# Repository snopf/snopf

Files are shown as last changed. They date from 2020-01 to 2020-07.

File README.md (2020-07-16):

# Snopf USB password token

> Info: The password creation algorithm for Snopf has been fundamentally changed since 6b1df42b0c21d2e936d6018c70f1937114251a39. The new firmware and the new tools and account table files aren't compatible with the former version. The command line tool has been deprecated. Snopf also switched from using a 128 bit secret to using a 256 bit secret on the device. For upgrading the firmware you can use the firmware updater from the bootloader repository [here](https://github.com/Snopf/Snopf_bootloader). For installation and configuration follow this readme.

## What is Snopf?

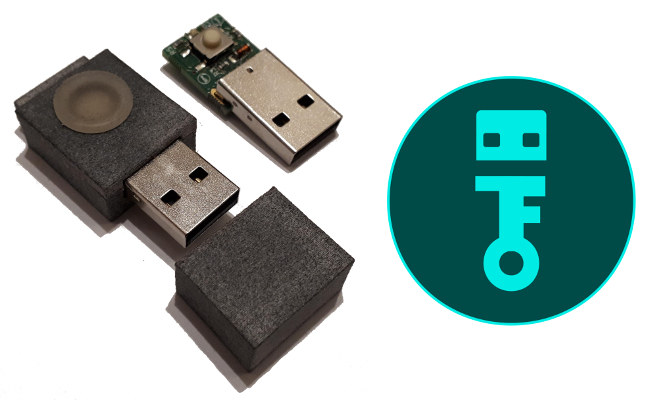
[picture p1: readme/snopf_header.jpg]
Snopf device


Snopf is a very simple, yet effective and easy to use USB password tool. The Snopf USB device creates a unique and strong password for every service from the same 256 bit secret which never leaves the token.

Whenever Snopf is plugged into the computer you can make a password request and then the red LED will light up. If you press the button within 10 seconds Snopf will imitate a keyboard and type the password for the requested service.

Snopf is designed as a hardware-based password generator to tackle the security issues most commonly encountered with stored passwords on ordinary PCs, such as reading of password files by malware or browser exploits. It generates passwords deterministically from a securely kept master secret unaccessible to software running on the host. 

For more details on security and how it works, see the section *Security considerations* and *Operation principle* below.
Instructions on how to build your own are found in the section *Hardware* and *Building the Firmware and Host Software*. A short manual on how to use Snopf after you installed the software is found in *How to use it*.

## Advantages of Snopf

* Very simple and robust design
* Easy to use
* You don't have to remember any passwords anymore (except preferably a master PIN for Snopf)
* Every password is unique and as strong as the accessed service allows
* The actual password creation is only happening on the USB device
* It is (under certain restrictions) possible to restore all passwords from a 24 word mnemonic representing the 256 bit secret
* It's more secure than a common pure software based password manager because the password creation is physically detached from the computer
* As Snopf emulates a regular keyboard, no passwords are stored in the clipboard

### Advantage over Common Software Password Managers
Common software password managers are very good tools to create and manage strong passwords for all your logins. Still, there is a possibility of your computer being remotely attacked and an attacker is able to access your password database getting all your login credentials.
Snopf is an improvement over these managers because an attacker can't access your Snopf token remotely. All passwords are derived from the secret on the device which an attacker must have phyiscal access to. So there is an additional *physical barrier* for an attacker.

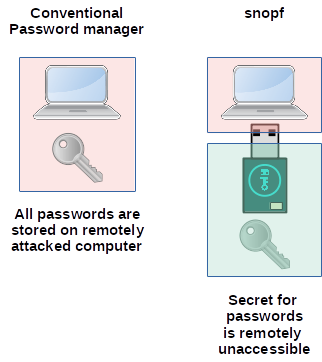
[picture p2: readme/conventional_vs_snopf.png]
conventional_vs_Snopf


## Using Snopf
A default request process for a password is pictured below, using the Snopf browser extension:

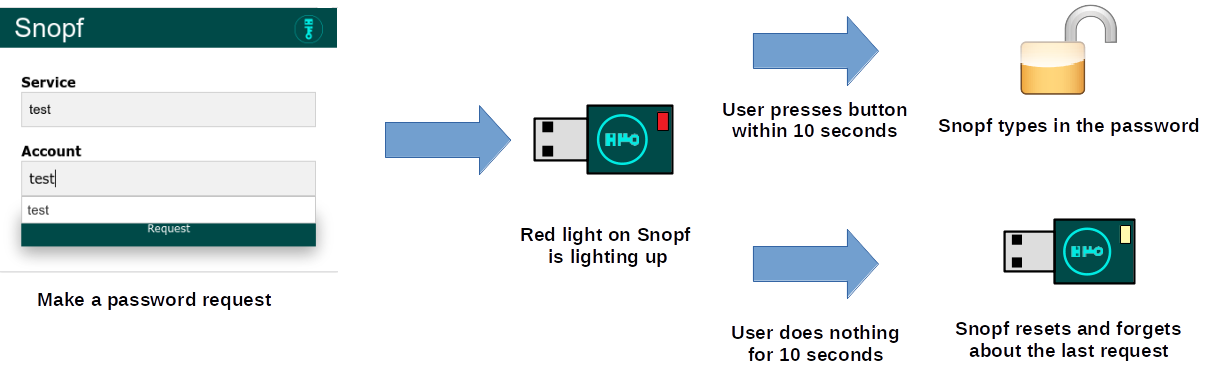
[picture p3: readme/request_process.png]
request_process


To use Snopf two tools are currently available (an additional Android App is being developed), the *Snopf Manager* and a browser extension.

The Snopf Manager needs to be running on a computer when using Snopf. Beside managing the account table for snopf (see below) it also runs a background server for the browser extension. Whenever a password request is made in the browser, it is sent to the server which in turn talks to the USB device. The Snopf Manager minimizes to tray and runs silently in the background if you are not currently editing the account table. You can also create new entries in the account table from the browser extension.

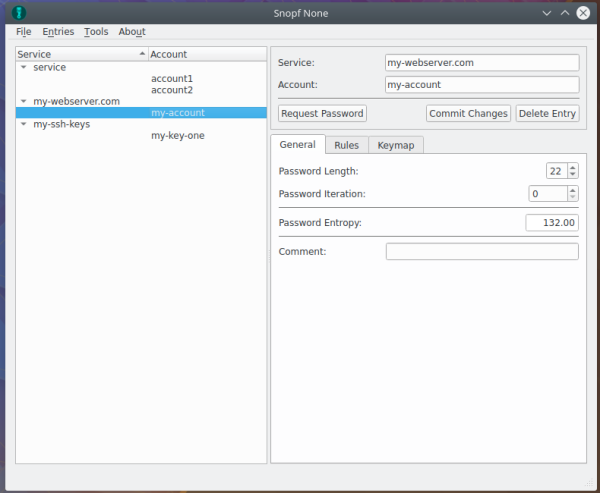
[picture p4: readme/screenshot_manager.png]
snopf manager screenshot


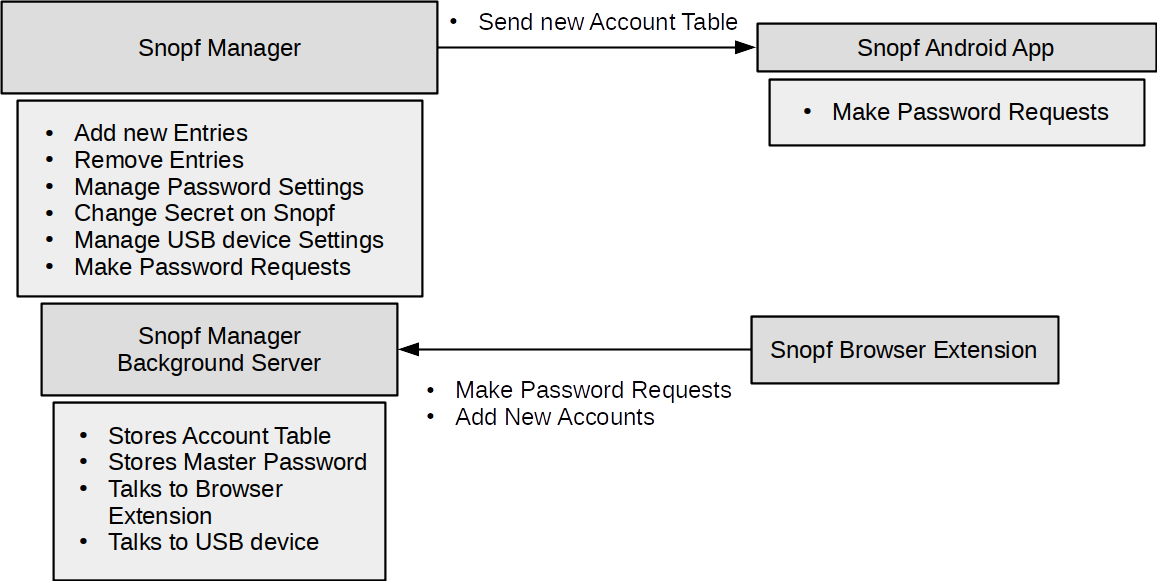
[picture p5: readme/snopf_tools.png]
snopf tool overview


### Account table
With Snopf Manager you can create new entries, delete entries and change entries in the account table. A Snopf account table is a simple json with entries for every unique (service, account) combination. Each entry has six fields:

1. `Service` = Hostname or service name for the login, for example the email service `examplemail.com`
2. `Account` = Your account at this service, for example the email address for the email service `my_mail_address@examplemail.com`
3. `Password length` = The password length you set for this service
4. `Password iteration` = An integer for every unique (service, account) combination which you increase if you have to set a new password for this combination for example after a databreach at the used service.
5. `Rules` = Rules for password creation, for example 'The password must include a lowercase character'
6. `Keymap` = A keymap which will be used for the password creation which allows to include and exclude certain characters

The account table file is AES encrypted on the hard disk using the same master password (not to be confused with the secret on the USB device!) that is used whenever a password request is submitted.

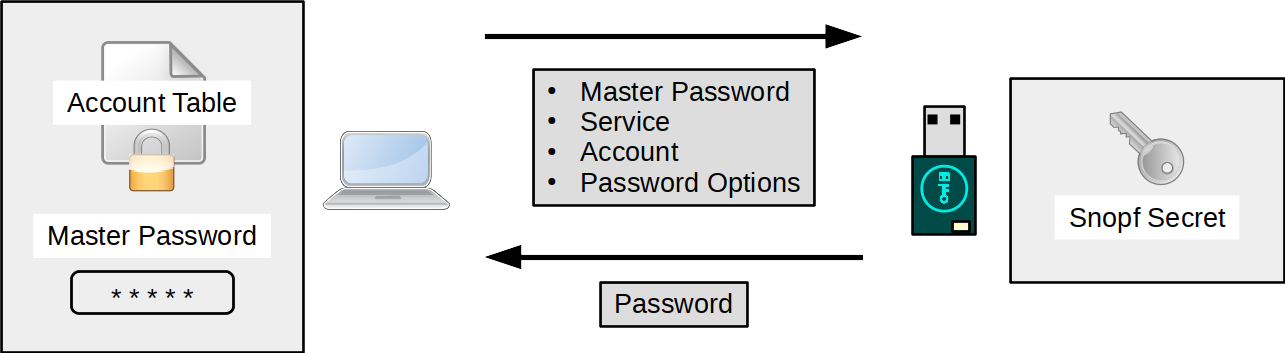
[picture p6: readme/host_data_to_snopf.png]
host_data_to_snopf


#### Setting the secret
You can change the secret on the Snopf device using Snopf Manager.

## Restoring passwords

To restore passwords, for example after losing or damaging Snopf, you need to be in possesion of the following data:

1. The Snopf's secret (comfortably as a 24 word mnemonic)
2. The optional master password (if you used one)
3. The account table

You might not absolutely need the account table if you have your logins, like email address and email service in your memory and just used passwords with default settings. Even if you need to remember *password iteration* you can just try out low numbers there.

Apart from that it is strongly advised to backup the account table and use a master password that you can remember. You should write down the 24 word mnemonic for the Snopf secret and store at a safe place.

With the above information you will be able to recreate all your passwords.

## Security considerations
Snopf isn't 100 % secure and a certain tradeoff between security, usability and economics has been made. Make sure to use Snopf only with your own or trusted PCs. It is also assumed that an adversary does not come into physical possesion of your Snopf. However, in case Snopf gets lost or is stolen, a reasonable safe master passphrase (the two-factor authentication approach) will still fend off or at least slow the attacker, depending on the strength of this passphrase.

Snopf has not been designed or further analyzed vs. more advanced attacks such as power analysis or timing side-channel attacks and could be theoretically vulnerable to either. Attacks of this and similar kinds are deemed outside the scope of the threat model that Snopf defends against. So far, regular computers don't seem to allow detailed current measurement at their USB ports which could potentially be used for remote attacks. More sophisticated attacks such as relying on analyzing the microcontroller's electromagnetic emissions are not deemed a common threat.
Timing attacks are similarly not expected to be a huge issue. The SHA256 crypto primitive used by Snopf runs in constant time. The iterated hashing to yield a password matching "password_valid" will cause some timing variation for a minority of passworts. However, as Snopf relies on a *manual* button press for replying with the password, a large amount of noise is added and makes analyses along this line a lot less feasible.

The ATtiny85 does not include a secure enclave (or similar) and reading out the microcontroller might be possible if an attacker has physical access. It can be made harder by setting the lockbits for the AVR but a capable attacker will be able to access the EEPROM data (where the secret is stored) eventually. A reasonable safe master passphrase will still prevent logins by an attacker at least for some time to create new passwords.

Passwords typed in by Snopf can of course still be intercepted by a keylogger and might land in the RAM and swap memory of the host where malware might access them. Covering those attack vectors is likewise out of scope for Snopf.
 
## Password Creation Algorithm
The password creation algorithm is explained in-depth [here](readme/password_algo.pdf).

## Hardware
You can find a KiCad project for Snopf in the `hardware` subfolder and also a PDF of the current schematic [here](https://github.com/Snopf/Snopf/blob/master/readme/schematic.pdf). The KiCad project also includes a PCB layout for a SMD version.

Bill of materials for the SMD version:
* ATTINY85-20SU SO(1)
* Resistor 10k 0603 (1)
* Resistor 220R 0603 (1)
* Resistor 1k 0603 (1)
* Resistor 1k5 0603 (1)
* Resistor 68R 0603 (2)
* Capacitor 18pF 0603 (2)
* Capacitor 100n 0603 (1)
* Capacitor 4u7 0805 (1)
* Crystal 12 Mhz 4 Pin (1)
* LED red 0603 (1)
* USB connector (1)
* Zener Diode 3,6V Mini Melf (2)
* Button Panasonic EVQQ2 (1)

There are links for Mouser parts that work for the PCB layout to be found in the KiCad schematic.

## Casing
A 3D printable casing can be found at `hardware/casing` both as a FreeCAD file and as four STEP files (bottom, top, button and a cap for the USB plug). The button is designed as a silicone button so that the diffuse LED light can been seen through it.
The dimensions of the casing are 41.9 x 19.4 x 11 mm.

## Running and building the Snopf software

### Python Venv
To avoid bugs and conflicts due to different versions of installed python packages it is advised to initialize a Python virtual enviroment for all operations described in this section. This includes running the python code as well as building binaries for either the AVR or the PC. Alternatively you can have a look at `src/py_requirements.txt` to see which Python packages and which versions are used for Snopf and install them accordingly.
To create a Python Venv you can simpy run
```
$ ./setup_py_env.sh
```
in the Linux console and
```
$ ./setup_py_env.ps1
```
in the Windows PowerShell. This will create a `.venv` directory with all necessary packages installed and activate that virtual enviroment for the current session.
To activate the virtual enviroment for the current session you run
```
$ source .venv/bin/activate
```
in the Linux console and
```
$ ./.venv/scripts/activate.ps1
```
in the Windows PowerShell.

### Linux udev rule
There is an udev rule for allowing USB acces to Snopf located in `src/host` which you can copy to `/etc/udev/rules.d` or you can simply run
```
$ ./install_usb_rule.sh
```

### Building the Firmware
You can compile the AVR code and program the AVR using the standard GNU toolchain using
```
$ make program
```
in the avr source directory `src/avr`. You'll probably have to alter the `Makefile` for your kind of programmer.

There also exists a bootloader written for this project, you can find it here [Snopf bootloader](https://github.com/Snopf/Snopf_bootloader) so that you can update the code on the device via USB. The bootloader is not necessary but it comes in handy for updating the firmware.

### Running the Snopf Manager Python code
After activating the Python virtual enviroment you can run the QT app as a Python script by running
```
python snopf.py
```
in `src/host/pc`.

### Building Snopf Manager Binaries for Linux
You can build a stand-alone binary for Snopf using PyInstaller. Just run `make` in `src/host/pc`.
It is advised to run `make` in the Python virtual enviroment to ensure that all needed packages are installed using the correct version.
The output will be created in `src/host/dist`.

### Building Snopf Manager Binaries for Windows
You can build an executable for Windows using the same Makefile as for Linux. You will have to have [GNU make for Windows](http://gnuwin32.sourceforge.net/packages/make.htm) installed. All scripts are written for PowerShell so you have to run Make from PowerShell.
PyInstaller will look for an [UPX](https://upx.github.io/) installation at `3rdparty/upx/`. You can create the binaries with or without using UPX compression.

### Browser extension
The firefox extension is located at `src/host/browser_extension` and can be packed into a zip file suitable for the browser by simply running `make` there.

There doesn't exist a signed version for the firefox browser extension yet so to permanently install the addon you would have to change the firefox settings  explictly to allow the installation of unsigned addons.
If you know what you are doing you can do this (for most firefox versions) by opening the 
```
about:config
```
page and set the value for 
```
xpinstall.signatures.required to false.
```
After doing that you can install the zip file under *about:addons*. If you change the setting back to *true* the addon will be deactivated by firefox.

Alternatively you can also temporarily install the addon by entering
```
about:debugging#/runtime/this-firefox
```
into the adress bar and and clicking *Load Temporary Add-on...*.

### Android App
An Android App is in development for the new Snopf algorithm.
<!-- 
The Android App is located at `src/host/android` as an project for `androidstudio` and can be build and applied to an Android phone using the same.
 -->

## Disclaimer
There is no warranty for data security and integrity or security issues of any kind. Care has been taken to make this a device that increases your security, however security bugs are possible.

You are free to use it and copy it but it comes **without any guarantees**.

## Links

* Snopf makes use of the excellent [V-USB driver](https://www.obdev.at/products/vusb/index.html)
* Article about Snopf on [Hackaday](https://hackaday.com/tag/snopf/)

## License
All code and schematics / hardware layouts are licensed under GNU General Public License (GPL) Version 2, see file License.txt.

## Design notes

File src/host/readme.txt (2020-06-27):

To build all programs (qt-tool, browser extensions) just use (being in the python venv!)
$ make

To build specific tools go to the subfolders and run
$ make tool

All binaries are put into dist/

USB rule installation (Linux):
To use the snopf device you should create an entry in /etc/udev/rules.d.
You can just run 
$ sudo ./install_usb_rule.sh
(Needs root privileges for writing to /etc/)

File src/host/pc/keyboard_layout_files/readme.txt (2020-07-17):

This directory contains files for different keyboard layouts that can be programmed into
the Snopf device.

Each file is a json file that includes a tuple of integers (first is key modifier, second is keycode) for each of the 64 characters in the Snopf character table.

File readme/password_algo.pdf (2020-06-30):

## Snopf Password Creation Algorithm

Hajo Kortmann

June 30, 2020

Snopf uses a deterministic algorithm for generating unique and strong passwords for every user login. The only crypto primitive used for generating passwords is SHA256 hashing, every password is essentially a SHA256 hash of the concatenation of the 256 bit secret stored on the Snopf device and a 128 bit request message which is unique for each password request.
Some services have different rules for valid passwords, for example the password must include a special character or a number. Passwords are iteratively generated until the created password meets the specific requirements for a given password request.

Variables

We introduce the short names S for the 32 byte secret on the Snopf and W for the final result of the password creation algorithm. W is a sequence of printable characters.

Data sent by the Host

For every password request the host must send the following data to the device:

1. M, the unique request message, a sequence of 16 bytes
2. l, an integer defining the length of the generated password
3. R, a set of the character inclusion rules (each rule is a set of characters)
4. rrep, boolean variable; if True the password must not include repeated characters (e.g. ’aa’)
5. rseq, boolean variable; if True the password must not include sequences of characters (e.g. ’abc’)
6. K, the keymap for the request, a sequence of integers of length 64

Request Message The request message must have a length of 16 bytes. It is defined as

M := first 16 bytes of SHA256 (service || account || master_passphrase || iteration)

Here service is the name of the service we want to log in to, account is our username or other account identifier for the service. The master_passphrase is a passphrase we use for all passwords

1

(might also be empty if the user doesn’t want to use a master passphrase)¹
. The iteration field
is a number for each unique (service, account) combination that is incremented every time a new password has to be created for a service, for example after a data breach at that service. The fields for master_passphrase, service and account are UTF-8 encoded strings without any terminating character like newline or null. iteration is an ASCII string representing the iteration integer.

Password Length The integer l ∈ {6, 7, .., 42} is the length of the generated password. As we use 6 bit for each character and the SHA256 hash is 256 bits long we get the upper limit of 42 characters for the password. The reasoning for the lower boundary is stated below in the section ‘Probability of Algorithm Convergence’.

Character Inclusion Ruleset As many services demand passwords to include characters of certain character groups the ruleset R is submitted. The ruleset R may include any of the following sets of characters which define which characters must be included:

1. The password must include a lowercase character, Rlc = {‘a’, ‘b’, .., ‘r’}
2. The password must include an uppercase character, Ruc = {‘A’, ‘B’, .., ‘R’}
3. The password must include a numerical character, Rnum = {‘0’, ‘1’, .., ‘9’}
4. The password must include a special character, Rsc = {‘-’, ‘@’, .., ‘>’}

These character sets are later used to test whether the password includes any element of the submitted rules.

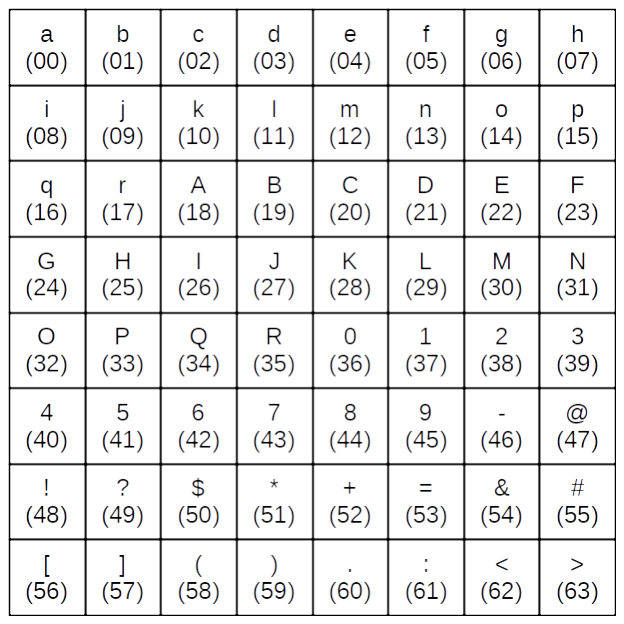
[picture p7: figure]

Figure 1: Snopf Character Set

Keymap The first step of processing the SHA256 output is the Base64²
transformation of the
hash digest into a sequence of integers in the range {0, 1, .., 63}. We could directly map this result

1Note that master passphrase and master secret are two independent variables. The master secret is the 256 bit secret stored on the Snopf device while the (optional) master password is a user input.
2Here we do not use the standard Base64 transformation definition where the output is a sequence of characters. The Base64 transformation in this context is the transformation of an input bit stream into a sequence of integers in the range {0, 1, .., 63} using 6-bit chunks of the input stream.

2

to a sequence of characters using the character table C shown in figure 1 but to allow the definite exclusion of characters from the output sequence we use the keymap K. Using K we simply map the k-th integer i from the Base64 sequence to the k-th character in W:

Wk = C(K(i))

We require 0 ≤ K(i) ≤ 63 for all 0 ≤ i ≤ 63.
While C and the Base64 transformation are both bijective this often won’t be the case for keymaps except the standard keymap where K(i) = i. For example, if we wanted to exclude all characters except lowercase letters the keymap would be defined as

Klc(i) = i mod 18

and for only numerical characters as

Knum(i) = (i mod 10) + 36

and so on. The keymap chosen thus influences the entropy per character of W, see below at ‘Password Entropy’.

Keymap validity for given rules The password creation rules defined above limit the creation of valid keymaps. If rrep is selected we obviously must have more than one value in K. To be able to avoid sequences we must either have a keymap with only one entry or more than two. For simplicity a keymap is defined as valid if it includes more than two different values.
Each value of K belongs to one of the four character groups (lowercase, uppercase, numerical, special character). The size of the subset of the image of K must be at least ten for every character group where a must-inclusion-rule is selected. This limit is needed to guarantee convergence of the iterative algorithm, see below in ‘Probability of Algorithm Convergence’.

## Iterative Password Algorithm

To create a valid password for a given request we use an iterative algorithm where we manipulate the first byte of the request message as often as needed until the SHA256 hash output will produce a valid password according to the selected rules.
First, we define the function replace_characters which, according to the submitted rules, replaces repetitions or sequences of characters. Note that this function only converges given the boundary conditions above about the size of the keymap.
Further, we define the function password_valid(W, R) which returns True if the password is valid according to the inclusion rules in R. A valid password includes at least one element of each set in R.
The iterative password generation algorithm assumes that all passed parameters guarantee the convergence of the algorithm in less than 256 iterations. We treat the request message M as an integer sequence M = (m0, m1, .., m15). To find a password we manipulate m0 until the SHA256 hash results in a valid password according to the rules. The probability of the convergence of this algorithm is calculated in the following section.

3

Algorithm 1: Repetition and sequence replacement
function replace_characters;
Input : Integer sequence B of Length l, Keymap K, Boolean variables rrep, rseq Output: Integer sequence B⁰ where every C(K(B⁰
i

)) 6= C(K(B⁰
i−1

)) if rrep = True and
every C(K(B⁰
i

)) 6= C(K(B⁰
i−1

) + 1) if rseq = True
B⁰
0

:= B0
foreach Bi

, 1 ≤ i < l do
B⁰
i

:= Bi
while [rrep ∧ (C(K(B⁰
i

)) = C(K(B⁰
i−1

)))] ∨ [rseq ∧ (C(K(B⁰
i

)) = C(K(B⁰
i−1

)) + 1)] do
Bi

:= (Bi + 1) mod 64
end
end

Algorithm 2: Password valid function
function password_valid;
Input : Password W of length l, Inclusion ruleset R
Output: True if password is valid according to ruleset R, else False Ws = {Wi

| 0 ≤ i < l}
for r in R do
if C ∩ r = ∅ then
return False
end
end
return True

Algorithm 3: Snopf password creation algorithm
Input : Secret S, Request Message M, Password Length l, Inclusion Rule set R, Repetition rule rrep, Sequence rule rseq, Keymap K Output: Character Sequence (Password) W of Length l
for 1 to 256 do
B64 := Base64(SHA256(S || M)) replace_characters(B64, rrep, rseq, K)
W := C(K(B64))
if password_valid(W, R) then return W
end
m0 = (m0 + 1) mod 256
end
return Failure

4

Probability of Algorithm Convergence

There is a – for the chosen boundary conditions only theoretical – chance for the password creation algorithm to fail or rather need an unreasonable number of iterations to find a valid password. We assume the process of finding a password to be following a geometric distribution since repeated SHA256 hashing of the manipulated data is assumed to be a memoryless process with uniform random output in this context. The probability p of a success at a single attempt is calculated from the experimentally found mean of needed attempts µ:

p = 1/µ

The probability of needing X ≤ n attempts for a success is then calculated by:

P(X ≤ n) = 1 − (1 − p)

n

To find µ, 100,000 passwords for each password length setting were created; with different random inputs for S and M at each try.
To test the worst case scenario all character inclusion rules were used for testing algorithm convergence (R = {Rlc, Ruc, Rnum, Rsc}). Also an unbalanced keymap was used, which included just 10 (minimum number) entries for three of the rules, thus lowering the chance for a certain character to be included in the output.
In table 1 we can see that there is only a theoretical chance for the algorithm to fail given the shortest possible password of length l = 6. For l > 6 we rarely need more than 2 tries to find a valid password.
Password length | mean | 1 − P(k = 1) | 1 − P(k ≤ 10) | 1 − P(k ≤ 255)
6 | 4.8 | 0.7922 | 0.0974 | 0.0
10 | 1.9 | 0.4748 | 0.5816e-3 | 0.0
20 | 1.1 | 0.0951 | 0.606e-12 | 0.0

Table 1: Probability of algorithm convergence

Password Entropy

The entropy of a password generated by Snopf depends on the length, chosen keymap and the selected rules. A password generated using the default settings (uniformly distributed keymap, no rules) results in a entropy of more than 128 bits for a password with a length of 22 characters. An entropy of 128 bit is deemed to be very safe for most passwords and 22 characters is short enough to be practical therefore the default password length setting is set to 22 characters. Whenever a a non-uniform keymap is used, the entropy per character is reduced and raising the password length might be advised.
Given the relative frequency x(k) for every k ∈ KI = {K(i) | i ∈ {0, 1, ..63}} the informational
entropy in number of bits for a single character is given by

Hc = −

X

k∈KI

x(k) log2 x(k)

and the entropy for a password is then obviously given by H = l · Hc.

5

Table 2 shows the entropy for some lengths and often used keymaps without extra rules. When password creation rules are enforced the resulting entropy will often be reduced. A solution for calculating the resulting entropy for any given keymap and a non empty rule set has not been found yet by the author. Snopf shows a warning in the GUI whenever rules are active, that the shown password entropy is a rough guess and will be lower in reality.

Keymap | Keymap set size | H for l = 1 | H for l = 6 | H for l = 22 | H for l = 42
All | 64 | 6.0 | 36 | 132 | 252.0
Alphanumerical | 46 | 5.44 | 32.63 | 119.63 | 228.38
Letters | 36 | 5.14 | 30.75 | 112.75 | 215.25
Lowercase Uppercase only | 18 | 4.16 | 24.93 | 91.42 | 174.54
Hex | 16 | 4.0 | 24.0 | 88.0 | 168.0
Numerical | 10 | 3.32 | 19.91 | 72.99 | 139.35

Table 2: Password entropy for different keymaps

6

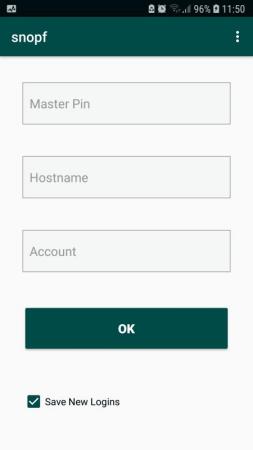
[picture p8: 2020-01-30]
readme/screenshot_android.jpg

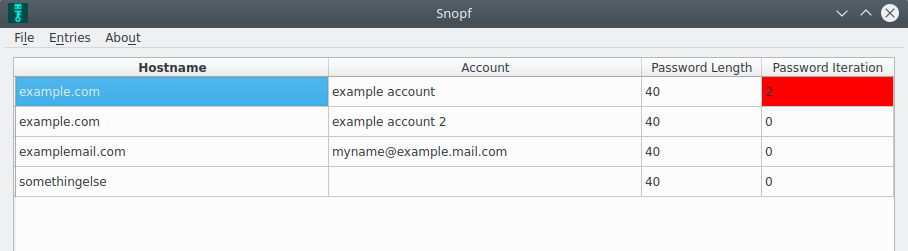
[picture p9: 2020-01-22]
readme/snopf_manager.png

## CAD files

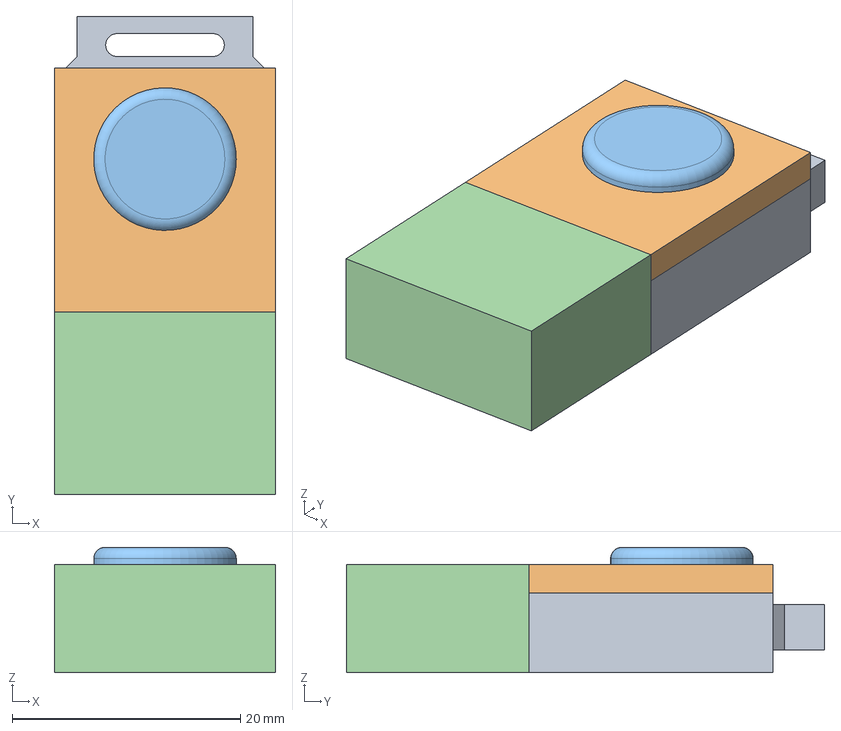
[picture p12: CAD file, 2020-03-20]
hardware/casing/casing.FCStd
19.4 x 41.9 x 11.0 mm
bottom
top
button
cap

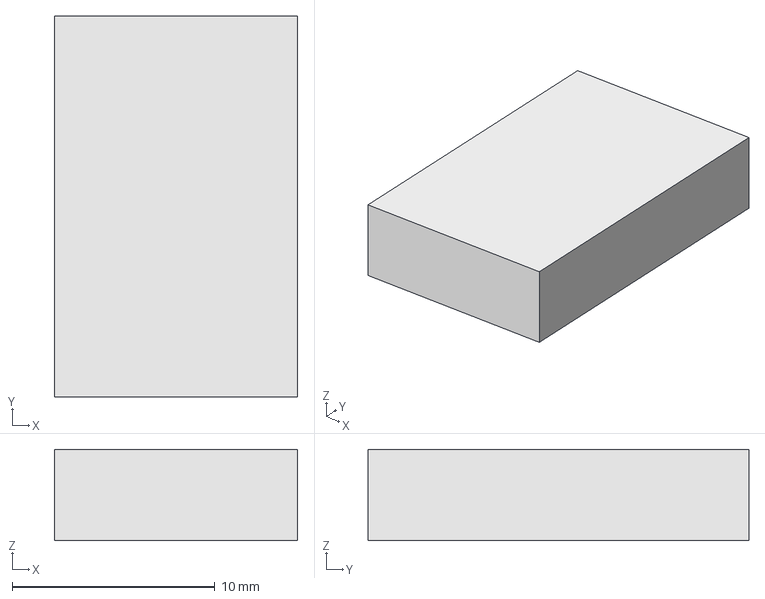
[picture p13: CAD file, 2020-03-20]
hardware/kicad/3d/UP2-AH-TH.step
12.0 x 18.8 x 4.50 mm

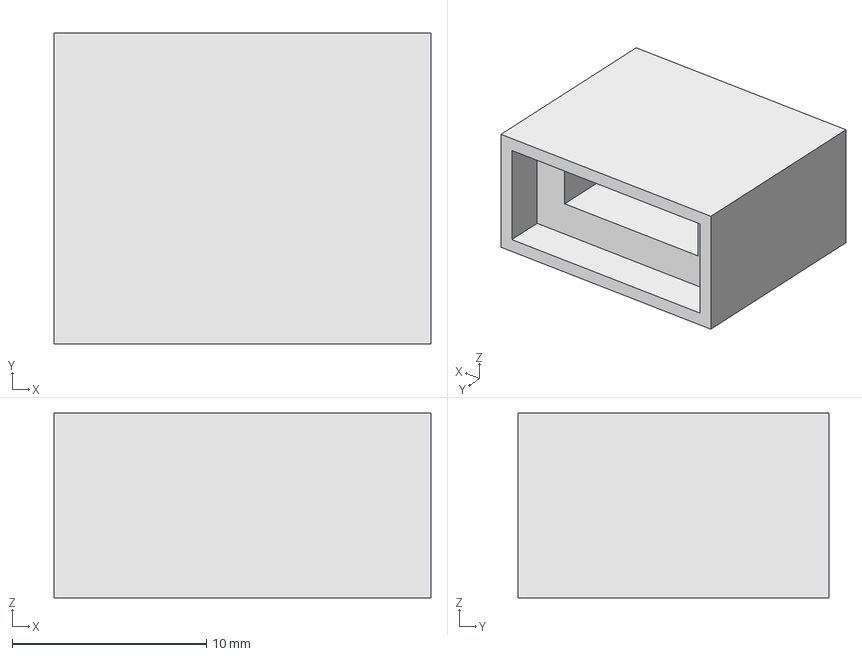
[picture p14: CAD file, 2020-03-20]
hardware/casing/cap.step
19.4 x 16.0 x 9.50 mm

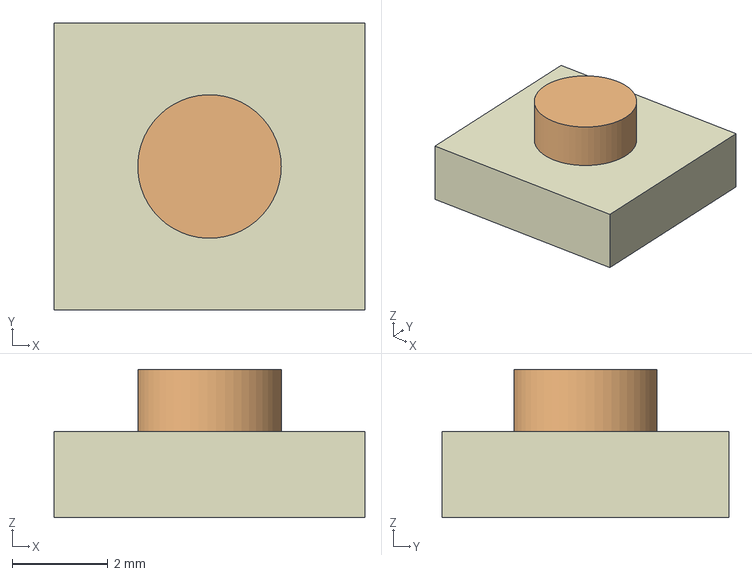
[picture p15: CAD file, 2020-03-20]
hardware/kicad/3d/EVQQ2B03W.step
6.50 x 6.00 x 3.10 mm

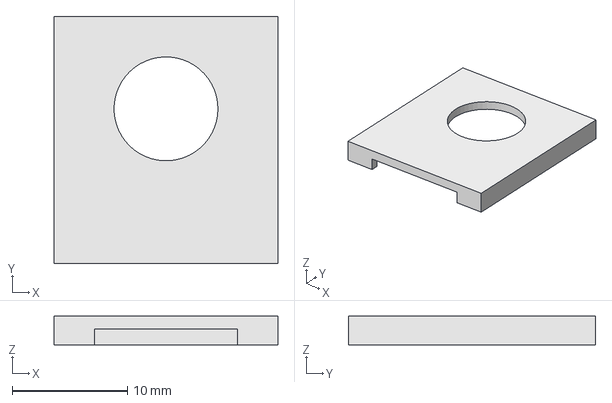
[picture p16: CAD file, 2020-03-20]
hardware/casing/top.step
19.4 x 21.4 x 2.50 mm

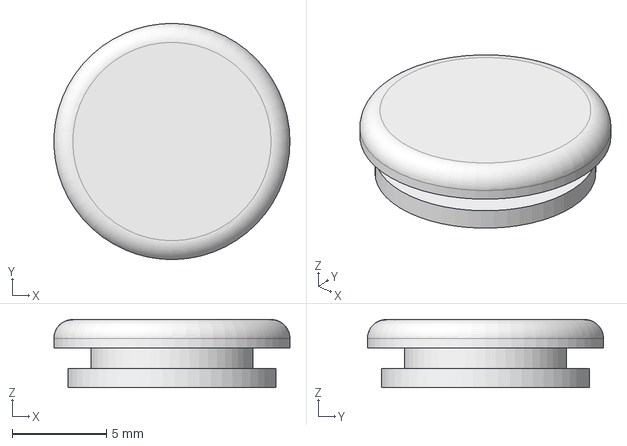
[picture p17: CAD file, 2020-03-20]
hardware/casing/button.step
12.5 x 12.5 x 3.60 mm

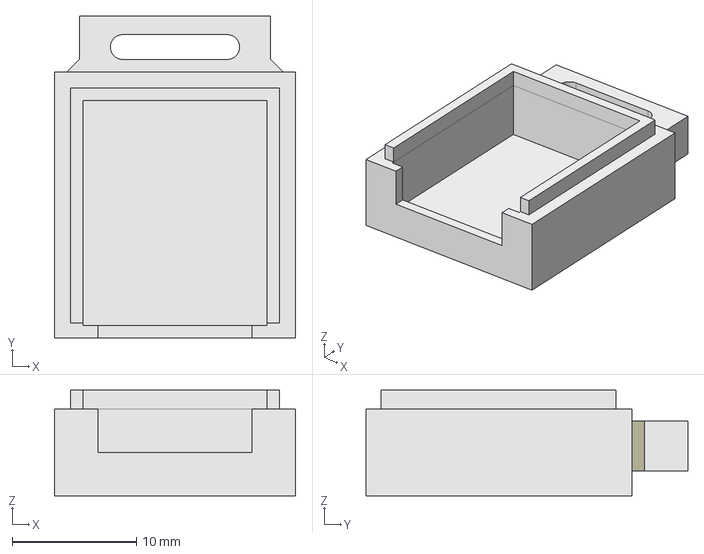
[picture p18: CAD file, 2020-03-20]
hardware/casing/bottom.step
19.4 x 25.9 x 8.50 mm

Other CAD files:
hardware/kicad/3d/UP2-AH-TH.FCStd
hardware/kicad/3d/evqq2b03w.FCStd

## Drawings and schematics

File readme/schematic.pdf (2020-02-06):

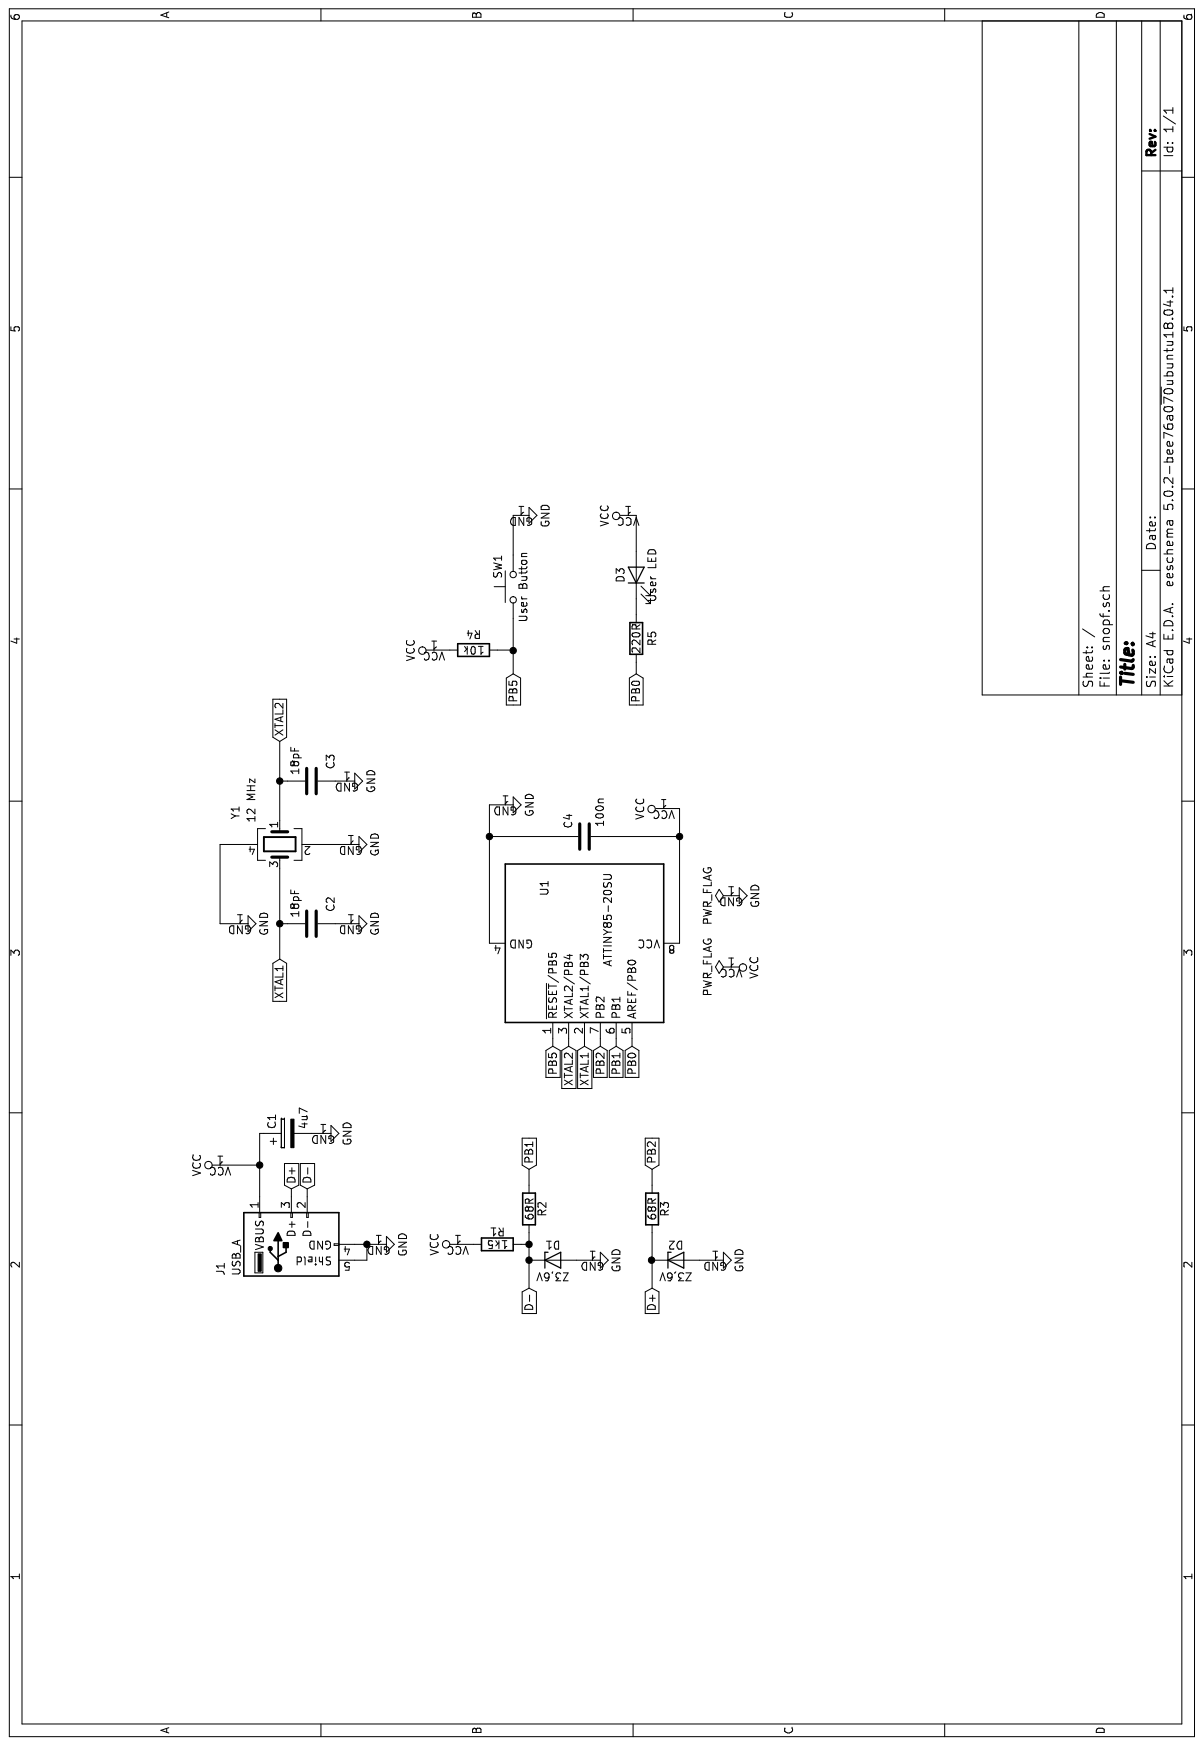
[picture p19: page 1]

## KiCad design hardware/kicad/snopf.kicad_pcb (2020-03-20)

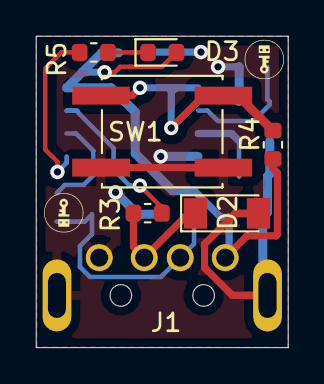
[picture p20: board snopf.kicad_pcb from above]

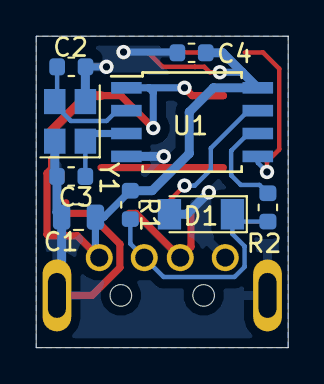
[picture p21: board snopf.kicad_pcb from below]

Board: 2 copper layers, 14.0 x 17.3 mm, 16 parts (9 on the bottom side), 11 nets.

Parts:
C1: 4u7; C_0805_2012Metric
C2, C3: 18pF; C_0603_1608Metric
C4: 100n; C_0603_1608Metric
D1, D2: Z3,6V; D_MiniMELF
D3: User LED; LED_0603_1608Metric
J1: USB_A; USB_plug_UP2-AH
R1: 1k5; R_0603_1608Metric
R2, R3: 68R; R_0603_1608Metric
R4: 10k; R_0603_1608Metric
R5: 220R; R_0603_1608Metric
SW1: User Button; SW_SPST_EVQQ2
U1: ATTINY85-20SU; SOIJ-8_5.3x5.3mm_P1.27mm
Y1: 12 MHz; Crystal_SMD_Abracon_ABM8G-4Pin_3.2x2.5mm

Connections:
D+: D2.1, J1.3, R3.2
D-: D1.1, J1.2, R1.2, R2.2
GND: C1.2, C2.1, C3.1, C4.2, D1.2, D2.2, J1.4, J1.5, SW1.2, U1.4, Y1.2, Y1.4
unnamed: D3.1, R5.1
PB0: R5.2, U1.5
PB1: R2.1, U1.6
PB2: R3.1, U1.7
PB5: R4.2, SW1.1, U1.1
VCC: C1.1, C4.1, D3.2, J1.1, R1.1, R4.1, U1.8
XTAL1: C2.2, U1.2, Y1.3
XTAL2: C3.2, U1.3, Y1.1

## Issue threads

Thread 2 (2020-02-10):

Will it work with off-the-shelf boards?

alfem, 2020-02-10:
I built a similar but more "primitive" device a few weeks ago, and I wonder if your code will work with one of these "DIYMORE" boards:

https://www.instructables.com/id/MicroKeyRing/

I am really bad in soldering, but your software if superior to mine by far, and I would like to give it a try.

snopf, 2020-02-10:
It should work, probably with some adjustments, with off-the-shelf boards. Somebody at hackaday suggested a digispark board with an ATiny85. The boards don't use a crystal so the software USB-driver had to be adjusted to using the on-chip oscillator, which afaik is working reliable most of the time.

If you want to try it out I could also send you one of the left-over pcb's from my last soldering session!

alfem, 2020-02-12:
My board (DIYMore Beetle) has got an ATMega32U4, and It can behave as a keyboard/mouse. It  works on every computer (Linux/Windows/Mac) I have tested BUT my work laptop (usb3 ports).

I'd love to test your board, if no soldering is required. How can I send you my address?

snopf, 2020-02-12:
Sent you an email!

Fazel94, 2022-10-18:
> ... a digispark board with an ATiny85...
Could you give a hint on how one can do it?
Can the crystal be attached by something over I/O port?

Closed 2020-02-12.

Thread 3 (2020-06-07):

Is it possible to write with arduino ide

mrguai, 2020-06-07:
Is it possible to write with arduino ide

snopf, 2020-06-08:
I don't know why it shouldn't be possible but I have no experience with Arduino and I guess it might be more complicated than using the standard gnu tools. Using AVR studio should be possible without any problems as well.
Do you mean compiling or flashing or both?

mrguai, 2020-06-08:
> I don't know why it shouldn't be possible but I have no experience with Arduino and I guess it might be more complicated than using the standard gnu tools. Using AVR studio should be possible without any problems as well.
> Do you mean compiling or flashing or both?

I am an arduino enthusiast and have no experience with AVR Studio.
I want to write hex to tiny85. Is it feasible to use ISP?

snopf, 2020-06-08:
Yes that should be possible.
If you want you can write the bootloader (https://github.com/snopf/snopf_bootloader) first (using ISP) and then you can upload the firmware hex using the firmware uploader python tool.

mrguai, 2020-06-08:
> Yes that should be possible.
> If you want you can write the bootloader (https://github.com/snopf/snopf_bootloader) first (using ISP) and then you can upload the firmware hex using the firmware uploader python tool.

ok
Your hardware has an external crystal oscillator, tiny85 doesn't seem to need a crystal oscillator, right?

snopf, 2020-06-08:
You can try without a crystal but you'll have to change the settings in the usb driver.

mrguai, 2020-06-09:
> You can try without a crystal but you'll have to change the settings in the usb driver.

ok

Closed 2020-06-11.

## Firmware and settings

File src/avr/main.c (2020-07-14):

// Copyright (c) 2019-2020 Hajo Kortmann <hajo.kortmann@gmx.de>
// License: GNU GPL v2 (see License.txt)

#include "usbdrv.h"
#include "usb_comm.h"
#include "io_stuff.h"
#include <avr/interrupt.h>
#include <util/delay.h>
#include <string.h>
#include "io_stuff.h"

int main(void)
{
    usbInit();
    io_init();
    // enforce re-enumeration
    usbDeviceDisconnect();
    _delay_ms(500);
    usbDeviceConnect();

    sei();

    while (1) {
        usbPoll();
        // Wait for a completed USB message
        if (usb_msg_recv) {
            if (!(usb_comm_process_message())) {
                io_failure_shutdown();
            }
            // Reset communication status to allow new messages
            usb_comm_reset();
        }
    }
    return 0;
}

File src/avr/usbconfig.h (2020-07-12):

/* Name: usbconfig.h
 * Project: V-USB, virtual USB port for Atmel's(r) AVR(r) microcontrollers
 * Author: Christian Starkjohann
 * Creation Date: 2005-04-01
 * Tabsize: 4
 * Copyright: (c) 2005 by OBJECTIVE DEVELOPMENT Software GmbH
 * License: GNU GPL v2 (see License.txt), GNU GPL v3 or proprietary (CommercialLicense.txt)
 * This Revision: $Id$
 */

#ifndef __usbconfig_h_included__
#define __usbconfig_h_included__

/*
General Description:
This file is an example configuration (with inline documentation) for the USB
driver. It configures V-USB for USB D+ connected to Port D bit 2 (which is
also hardware interrupt 0 on many devices) and USB D- to Port D bit 4. You may
wire the lines to any other port, as long as D+ is also wired to INT0 (or any
other hardware interrupt, as long as it is the highest level interrupt, see
section at the end of this file).
*/

/* ---------------------------- Hardware Config ---------------------------- */


#define USB_CFG_IOPORTNAME      B
/* This is the port where the USB bus is connected. When you configure it to
 * "B", the registers PORTB, PINB and DDRB will be used.
 */
#define USB_CFG_DMINUS_BIT      1
/* This is the bit number in USB_CFG_IOPORT where the USB D- line is connected.
 * This may be any bit in the port.
 */
#define USB_CFG_DPLUS_BIT       2
/* This is the bit number in USB_CFG_IOPORT where the USB D+ line is connected.
 * This may be any bit in the port. Please note that D+ must also be connected
 * to interrupt pin INT0! [You can also use other interrupts, see section
 * "Optional MCU Description" below, or you can connect D- to the interrupt, as
 * it is required if you use the USB_COUNT_SOF feature. If you use D- for the
 * interrupt, the USB interrupt will also be triggered at Start-Of-Frame
 * markers every millisecond.]
 */
#define USB_CFG_CLOCK_KHZ       (F_CPU/1000)
/* Clock rate of the AVR in kHz. Legal values are 12000, 12800, 15000, 16000,
 * 16500, 18000 and 20000. The 12.8 MHz and 16.5 MHz versions of the code
 * require no crystal, they tolerate +/- 1% deviation from the nominal
 * frequency. All other rates require a precision of 2000 ppm and thus a
 * crystal!
 * Since F_CPU should be defined to your actual clock rate anyway, you should
 * not need to modify this setting.
 */
#define USB_CFG_CHECK_CRC       0
/* Define this to 1 if you want that the driver checks integrity of incoming
 * data packets (CRC checks). CRC checks cost quite a bit of code size and are
 * currently only available for 18 MHz crystal clock. You must choose
 * USB_CFG_CLOCK_KHZ = 18000 if you enable this option.
 */

/* ----------------------- Optional Hardware Config ------------------------ */

/* #define USB_CFG_PULLUP_IOPORTNAME   D */
/* If you connect the 1.5k pullup resistor from D- to a port pin instead of
 * V+, you can connect and disconnect the device from firmware by calling
 * the macros usbDeviceConnect() and usbDeviceDisconnect() (see usbdrv.h).
 * This constant defines the port on which the pullup resistor is connected.
 */
/* #define USB_CFG_PULLUP_BIT          4 */
/* This constant defines the bit number in USB_CFG_PULLUP_IOPORT (defined
 * above) where the 1.5k pullup resistor is connected. See description
 * above for details.
 */

/* --------------------------- Functional Range ---------------------------- */
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

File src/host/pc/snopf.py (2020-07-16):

#!/usr/bin/env python3

# Copyright (c) 2020 Hajo Kortmann <hajo.kortmann@gmx.de>
# License: GNU GPL v2 (see License.txt)

import logging
from logging.handlers import RotatingFileHandler
from logging.config import dictConfig
import os
import sys
import appdirs
import getopt
#from PySide2.QtCore import QApplication
from PySide2.QtWidgets import *
from PySide2.QtGui import *

from snopf_manager import SnopfManager

def init_logging(path=None):
    global logFileHandler
    if not path:
        path = appdirs.user_log_dir('snopf-manager', 'snopf')
    if not os.path.exists(path):
        os.makedirs(path)
    log_file = os.path.join(path, 'snopf_log.log')
    logFileFormatter = logging.Formatter('%(asctime)s %(name)s %(levelname)s %(funcName)s(%(lineno)d) %(message)s')
    logFileHandler = RotatingFileHandler(log_file, maxBytes=10*1024, backupCount=5)
    logFileHandler.setFormatter(logFileFormatter)
    logFileHandler.setLevel(logging.INFO)
    logConsoleFormatter = logging.Formatter('%(name)s %(levelname)s %(funcName)s(%(lineno)d) %(message)s')
    logConsoleHandler = logging.StreamHandler()
    logConsoleHandler.setFormatter(logConsoleFormatter)
    logConsoleHandler.setLevel(logging.INFO)
    
    logging.root.setLevel(logging.INFO)
    logging.root.addHandler(logFileHandler)
    logging.root.addHandler(logConsoleHandler)
    
if __name__ == '__main__':
    opts, args = getopt.getopt(sys.argv[1:], 'c:l:')
    config_file_dir = None
    log_file_dir = None
    for o, a in opts:
        if o == '-c':
            config_file_dir = a
        elif o == '-l':
            log_file_dir = a
    init_logging(log_file_dir)
    app = QApplication([])
    w = SnopfManager(config_file_dir)
    w.show()
    sys.exit(app.exec_())

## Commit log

2020-01-22 Add schematic pdf to readme
2020-02-06 add wheel to py requirements
2020-02-06 Use reset button as button input
    [snopf.kicad_pcb, snopf.sch]
2020-02-07 fix entry insertion from browser extension
    the browser driver assumed the account table to be unchanged
    since start which could lead to data loss if accounts had been
    inserted using other tools
2020-03-20 Add a 3D printable casing
    [EVQQ2B03W.step, UP2-AH-TH.FCStd, UP2-AH-TH.step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]
2020-06-27 implement new password algorithm for avr and python/qt
    first implementation of the new snopf password algorithm for the
    usb device and a host qt application
2020-06-30 Redesign browser extension to use websocket for native communication
    [account_table.py, requests.py, snopf_manager.py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]
2020-07-04 catch usb error for insufficient permissions
    [snopf_manager.py]
2020-07-05 fix comment field (was readonly)
    [ui_snopf_manager.py]
2020-07-06 add windows powershell script for virtualenv init
2020-07-06 import QtSvg explicitly
    scg icons won't work on windows if we don't import QtSvg
    [snopf_manager.py]
2020-07-12 Replace pyusb with hidapi when running windows
    [avr_testing.py, main.c, test_websocket_server.py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]
2020-07-12 ps script for git commit inserting
2020-07-13 replace vendor request with hid report when using libusb
    [usb_comm.py]
2020-07-14 fix device lifetime in set_secret_wizard for hidapi use
    [set_secret_wizard.py]
2020-07-14 fix message lengths for windows
    [usb_comm.py]
2020-07-14 fix avr testing usb_comm import
    [avr_testing.py]
2020-07-14 fix text format for label for expected password
    [set_secret_wizard.py]
2020-07-15 fix websocket error connection
    [websocket_server.py]
2020-07-15 fix new entry creation after new account table creation
    [snopf_manager.py]
2020-07-17 add functionality for setting keyboard layout on usb device
2020-07-17 fix auto uppercase for validity check password field
    [ui_set_secret_wizard.py]
2020-07-23 decrease delay to make button more responsive
2020-08-04 fix request for new entry from websocket client
    [snopf_manager.py]
2020-08-05 fix newentry / deleted items order bug
    [account_table_model.py]
2020-08-05 reset model when saving
    [account_table_model.py]
2020-08-05 fix preset keymaps selection
    [keymap_editing.py, snopf_manager.py]
2020-08-27 fix order of websocket / account table loading
    we need to have a websocket server available whenever we load
    the account table file
    [snopf_manager.py]
